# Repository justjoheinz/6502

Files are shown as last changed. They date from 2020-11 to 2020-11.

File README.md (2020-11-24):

# 6502 Microcomputer

## Bill of materials

[BOM](6502.csv)

## Schematic

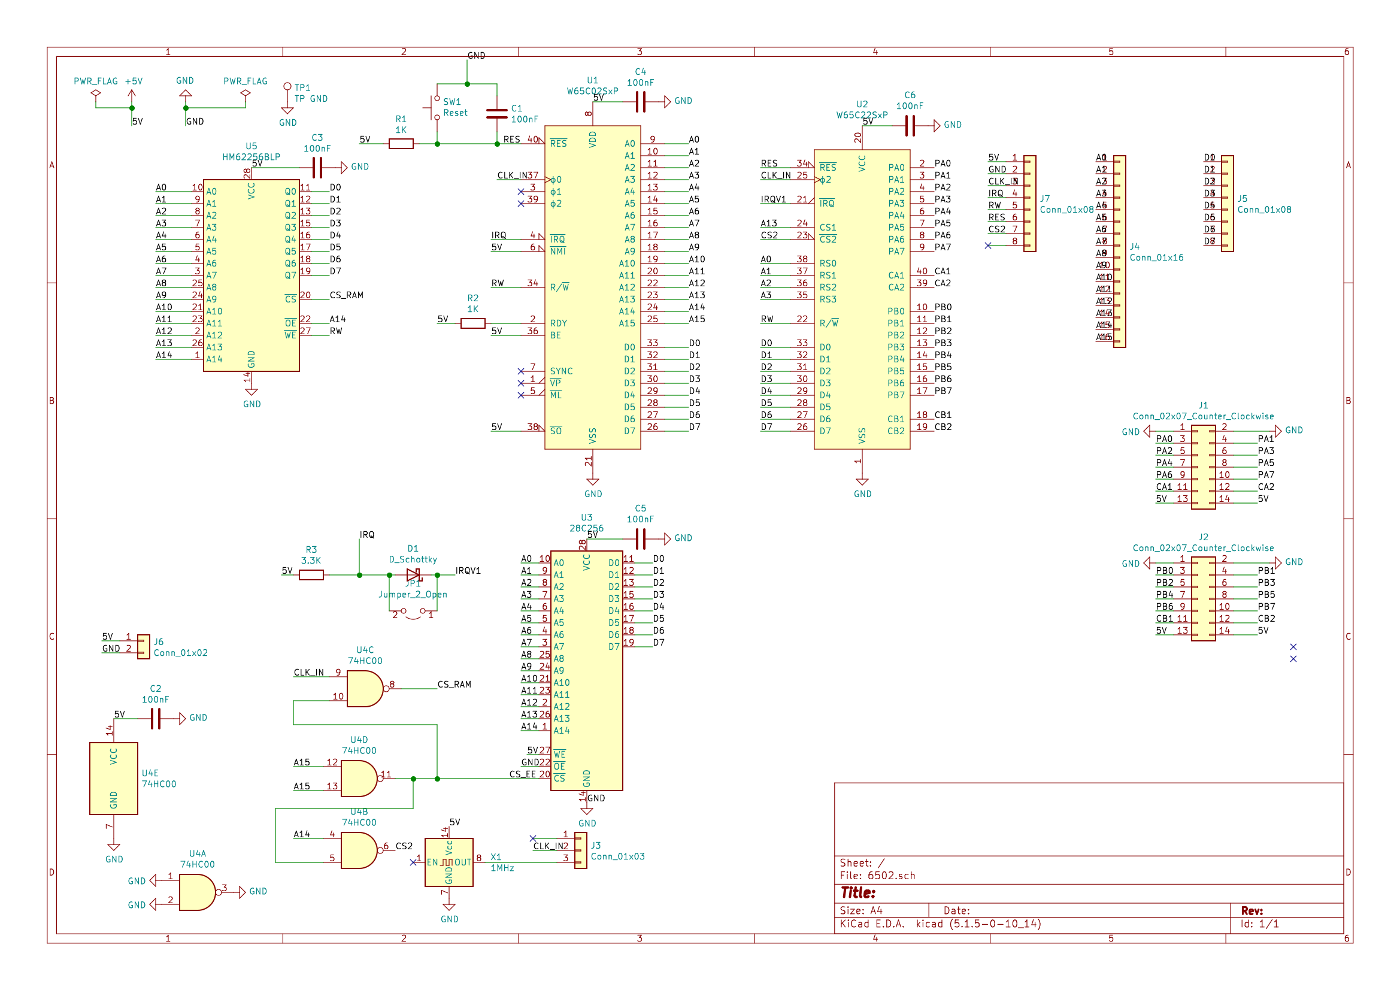
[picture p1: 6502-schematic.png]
Schematic


## PCB

### Mainboard

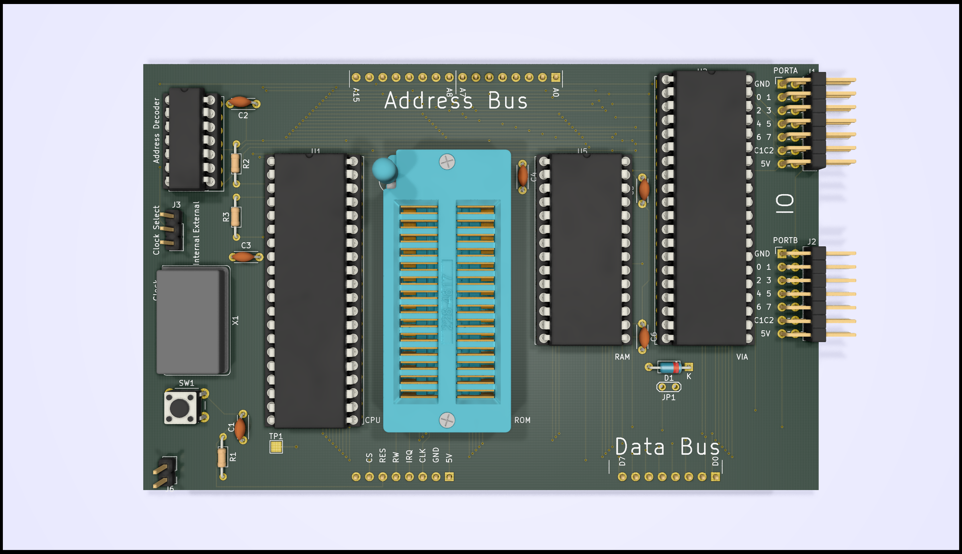
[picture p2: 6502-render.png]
Main board


### Prototype Board

Prototype Board

### Status

| Version | Status | Comment |
|---|---|---|
| v1.0.0  | unverified | boards send for production |

## Memory maps

| Type | From | To | Comments |
|---|---|---|---|
| RAM  | 0x0000 | 0x3FFF | |
| VIA  | 0x6000 | | A14, A15 - Registers via A0 - A3 |
| ROM  | 0x8000 | 0xFFFF | A15 High |

## ROM Source Code

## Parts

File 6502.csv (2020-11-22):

Comment | Designator | Footprint | LCSC Part #
100nF Unpolarized capacitor | C1,C2,C3,C4,C5,C6 | C_Disc_D4.3mm_W1.9mm_P5.00mm
D_Schottky Schottky diode | D1 | D_DO-35_SOD27_P7.62mm_Horizontal
Conn_02x07_Counter_Clockwise Generic connector, double row, 02x07, odd/even pin numbering scheme (row 1 odd numbers, row 2 even numbers), script generated (kicad-library-utils/schlib/autogen/connector/) | J1,J2 | PinHeader_2x07_P2.54mm_Horizontal
Conn_01x03 Generic connector, single row, 01x03, script generated (kicad-library-utils/schlib/autogen/connector/) | J3 | PinHeader_1x03_P2.54mm_Vertical
Conn_01x16 Generic connector, single row, 01x16, script generated (kicad-library-utils/schlib/autogen/connector/) | J4 | PinHeader_1x16_P2.54mm_Vertical
Conn_01x08 Generic connector, single row, 01x08, script generated (kicad-library-utils/schlib/autogen/connector/) | J5,J7 | PinHeader_1x08_P2.54mm_Vertical
Conn_01x02 Generic connector, single row, 01x02, script generated (kicad-library-utils/schlib/autogen/connector/) | J6 | PinHeader_1x02_P2.54mm_Vertical
Jumper_2_Open Jumper, 2-pole, open | JP1 | TestPoint_2Pads_Pitch2.54mm_Drill0.8mm
1K Resistor | R1,R2 | R_Axial_DIN0204_L3.6mm_D1.6mm_P7.62mm_Horizontal
3.3K Resistor | R3 | R_Axial_DIN0204_L3.6mm_D1.6mm_P7.62mm_Horizontal
Reset Push button switch, generic, two pins | SW1 | SW_PUSH_6mm
TP GND test point | TP1 | TestPoint_Pad_2.0x2.0mm
W65C02SxP W65C02S 8-bit CMOS General Purpose Microprocessor, DIP-40 | U1 | DIP-40_W15.24mm_Socket_LongPads
W65C22SxP W65C22S CMOS Versatile Interface Adapter (VIA), 20-pin I/O, 2 Timer/Counters, DIP-40 | U2 | DIP-40_W15.24mm_Socket_LongPads
28C256 Paged Parallel EEPROM 256Kb (32K x 8), DIP-28/SOIC-28 | U3 | DIP_Socket-28_W11.9_W12.7_W15.24_W17.78_W18.5_3M_228-1277-00-0602J
74HC00 quad 2-input NAND gate | U4 | DIP-14_W7.62mm_Socket_LongPads
HM62256BLP 32,768-word × 8-bit High Speed CMOS Static RAM, 70ns, DIP-28 | U5 | DIP-28_W15.24mm_Socket_LongPads
1MHz Crystal Clock Oscillator, DIP14-style metal package | X1 | Oscillator_DIP-14

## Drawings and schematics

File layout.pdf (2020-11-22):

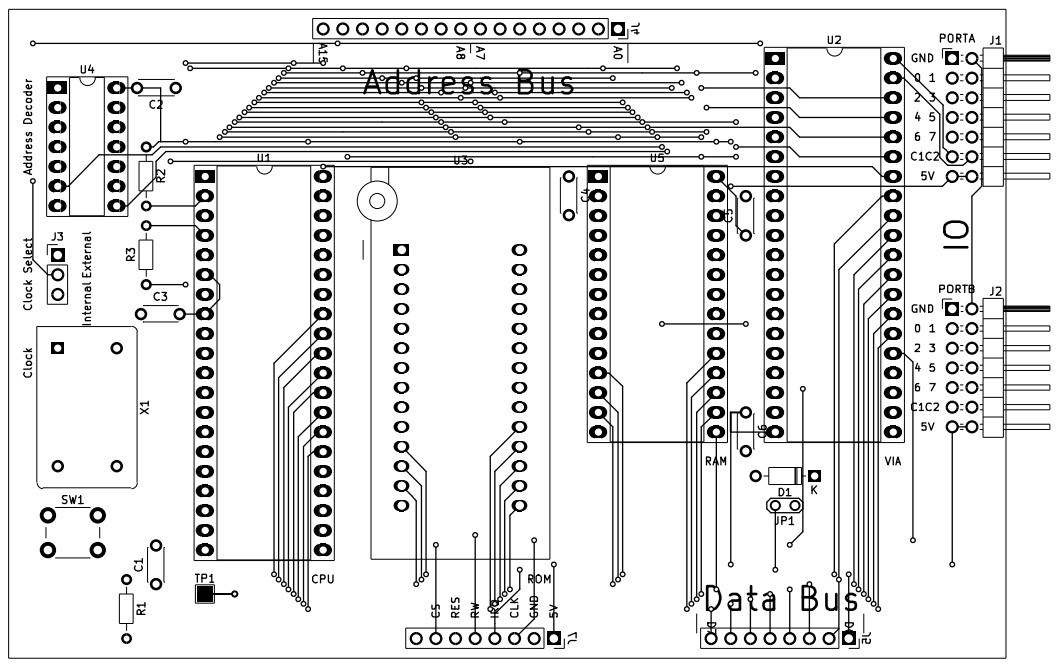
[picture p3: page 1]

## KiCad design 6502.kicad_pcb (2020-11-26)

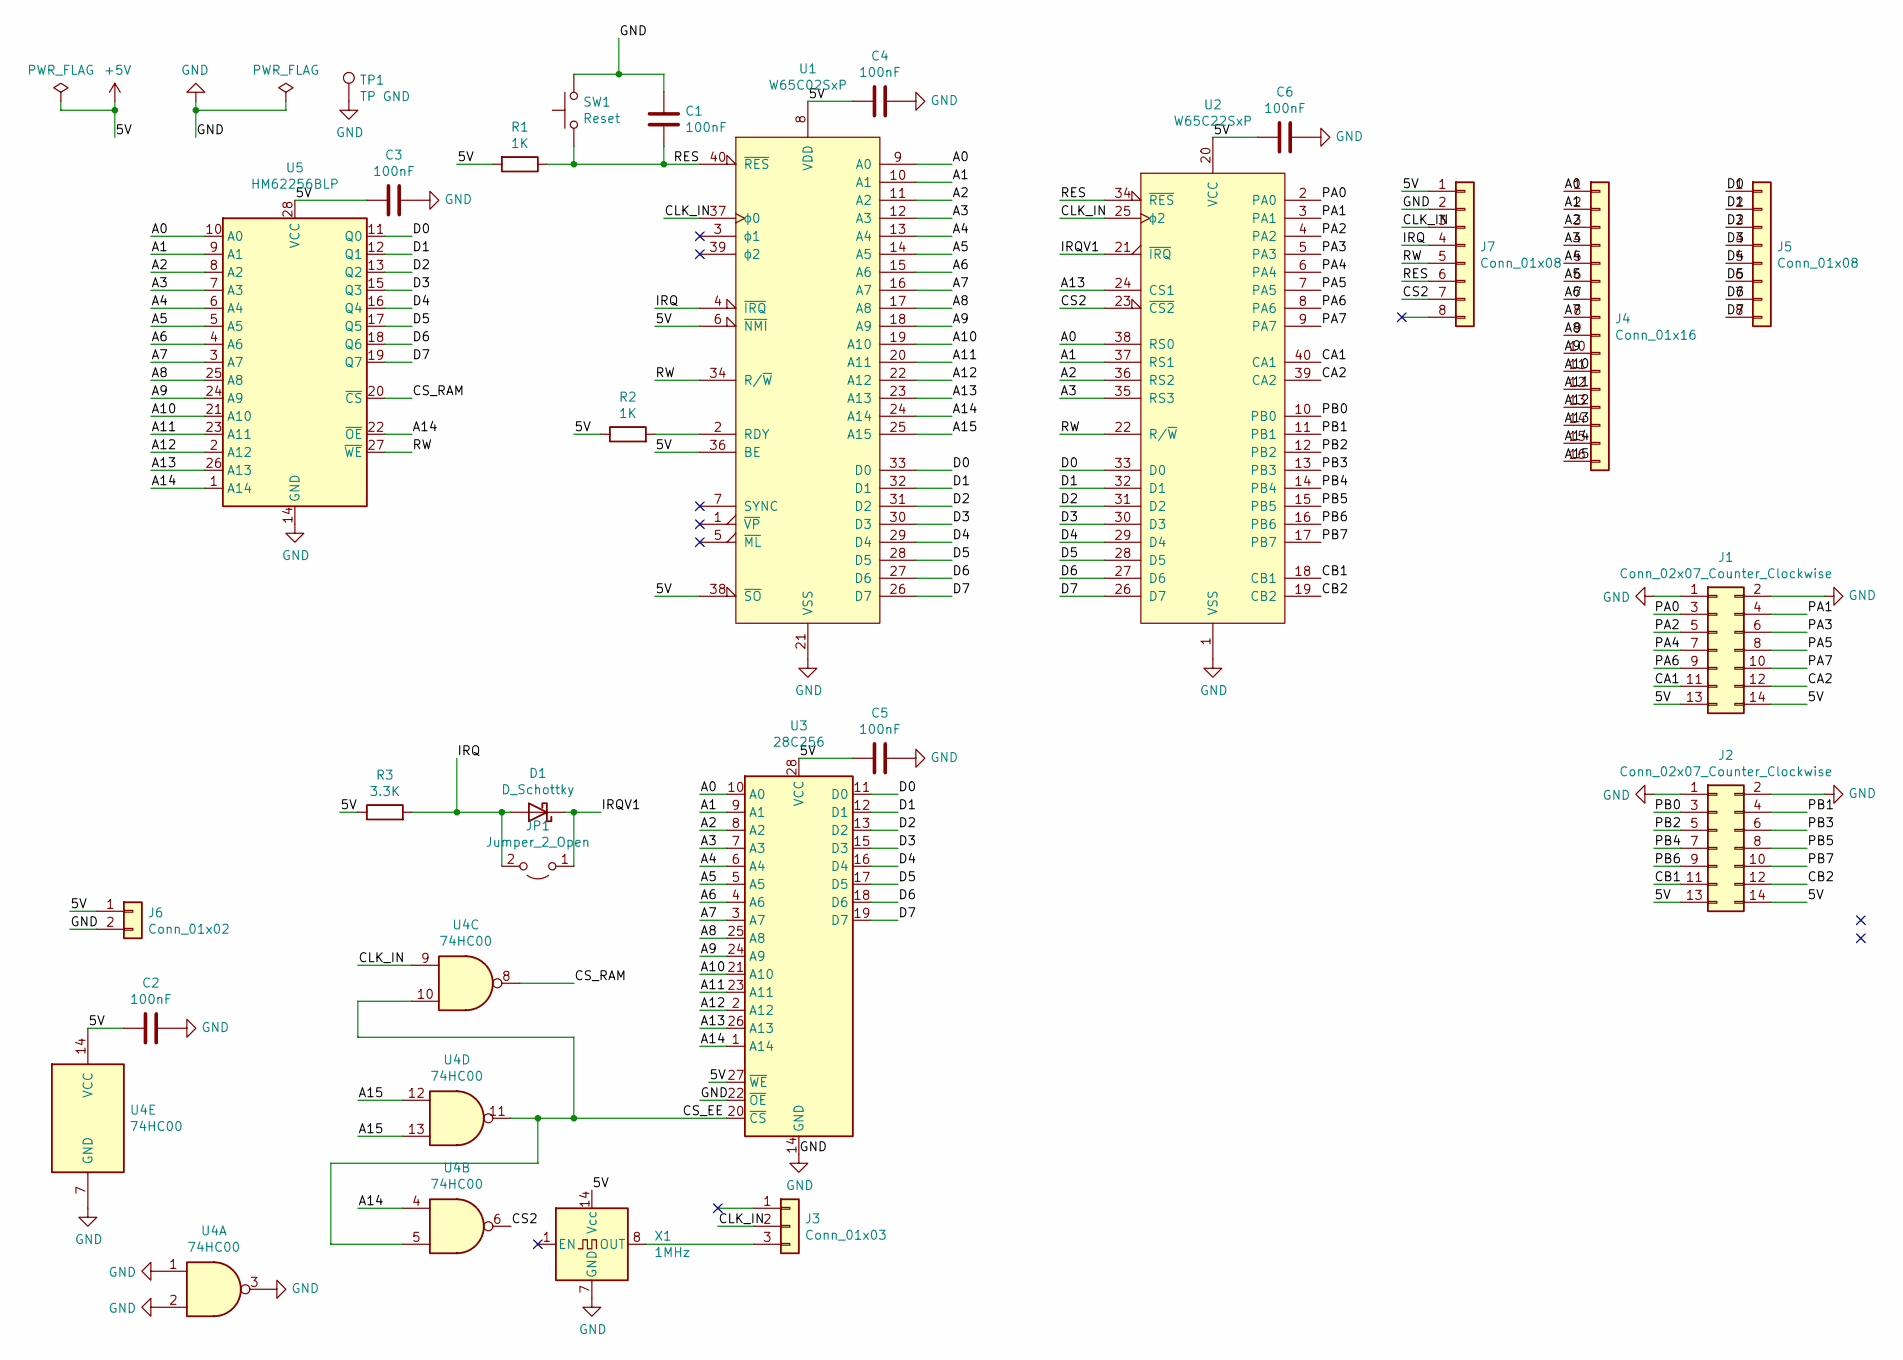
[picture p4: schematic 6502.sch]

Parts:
C1, C2, C3, C4, C5, C6: 100nF; C_Disc_D4.3mm_W1.9mm_P5.00mm
D1: D_Schottky; D_DO-35_SOD27_P7.62mm_Horizontal
J1, J2: Conn_02x07_Counter_Clockwise; PinHeader_2x07_P2.54mm_Horizontal
J3: Conn_01x03; PinHeader_1x03_P2.54mm_Vertical
J4: Conn_01x16; PinHeader_1x16_P2.54mm_Vertical
J5, J7: Conn_01x08; PinHeader_1x08_P2.54mm_Vertical
J6: Conn_01x02; PinHeader_1x02_P2.54mm_Vertical
JP1: Jumper_2_Open; TestPoint_2Pads_Pitch2.54mm_Drill0.8mm
R1, R2: 1K; R_Axial_DIN0204_L3.6mm_D1.6mm_P7.62mm_Horizontal
R3: 3.3K; R_Axial_DIN0204_L3.6mm_D1.6mm_P7.62mm_Horizontal
SW1: Reset; SW_PUSH_6mm
TP1: TP GND; TestPoint_Pad_2.0x2.0mm
U1: W65C02SxP; DIP-40_W15.24mm_Socket_LongPads
U2: W65C22SxP; DIP-40_W15.24mm_Socket_LongPads
U3: 28C256; DIP_Socket-28_W11.9_W12.7_W15.24_W17.78_W18.5_3M_228-1277-0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
U4: 74HC00; DIP-14_W7.62mm_Socket_LongPads
U5: HM62256BLP; DIP-28_W15.24mm_Socket_LongPads
X1: 1MHz; Oscillator_DIP-14

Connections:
+5V: C2.2, C3.2, C4.2, C5.1, C6.1, J1.13, J1.14, J2.13, J2.14, J6.1, J7.1, R1.2, R2.1, R3.1, U1.6 (~NMI), U1.8 (VDD), U1.36 (BE), U1.38 (~SO), U2.20 (VCC), U3.27 (~WE), U3.28 (VCC), U4.14 (VCC), U5.28 (VCC), X1.14 (Vcc)
/A0: J4.1, U1.9 (A0), U2.38 (RS0), U3.10 (A0), U5.10 (A0)
/A1: J4.2, U1.10 (A1), U2.37 (RS1), U3.9 (A1), U5.9 (A1)
/A2: J4.3, U1.11 (A2), U2.36 (RS2), U3.8 (A2), U5.8 (A2)
/A3: J4.4, U1.12 (A3), U2.35 (RS3), U3.7 (A3), U5.7 (A3)
/A4: J4.5, U1.13 (A4), U3.6 (A4), U5.6 (A4)
/A5: J4.6, U1.14 (A5), U3.5 (A5), U5.5 (A5)
/A6: J4.7, U1.15 (A6), U3.4 (A6), U5.4 (A6)
/A7: J4.8, U1.16 (A7), U3.3 (A7), U5.3 (A7)
/A8: J4.9, U1.17 (A8), U3.25 (A8), U5.25 (A8)
/A9: J4.10, U1.18 (A9), U3.24 (A9), U5.24 (A9)
/A10: J4.11, U1.19 (A10), U3.21 (A10), U5.21 (A10)
/A11: J4.12, U1.20 (A11), U3.23 (A11), U5.23 (A11)
/A12: J4.13, U1.22 (A12), U3.2 (A12), U5.2 (A12)
/A13: J4.14, U1.23 (A13), U2.24 (CS1), U3.26 (A13), U5.26 (A13)
/A14: J4.15, U1.24 (A14), U3.1 (A14), U4.4, U5.1 (A14), U5.22 (~OE)
/A15: J4.16, U1.25 (A15), U4.12, U4.13
/CA1: J1.11, U2.40 (CA1)
/CA2: J1.12, U2.39 (CA2)
/CB1: J2.11, U2.18 (CB1)
/CB2: J2.12, U2.19 (CB2)
/CLK_IN: J3.2, J7.3, U1.37 (ϕ0), U2.25 (ϕ2), U4.9
/CS2: J7.7, U2.23 (~CS2), U4.6
/CS_EE: U3.20 (~CS), U4.5, U4.10, U4.11
/CS_RAM: U4.8, U5.20 (~CS)
/D0: J5.1, U1.33 (D0), U2.33 (D0), U3.11 (D0), U5.11 (Q0)
/D1: J5.2, U1.32 (D1), U2.32 (D1), U3.12 (D1), U5.12 (Q1)
/D2: J5.3, U1.31 (D2), U2.31 (D2), U3.13 (D2), U5.13 (Q2)
/D3: J5.4, U1.30 (D3), U2.30 (D3), U3.15 (D3), U5.15 (Q3)
/D4: J5.5, U1.29 (D4), U2.29 (D4), U3.16 (D4), U5.16 (Q4)
/D5: J5.6, U1.28 (D5), U2.28 (D5), U3.17 (D5), U5.17 (Q5)
/D6: J5.7, U1.27 (D6), U2.27 (D6), U3.18 (D6), U5.18 (Q6)
/D7: J5.8, U1.26 (D7), U2.26 (D7), U3.19 (D7), U5.19 (Q7)
/IRQ: D1.2 (A), J7.4, JP1.2 (B), R3.2, U1.4 (~IRQ)
/IRQV1: D1.1 (K), JP1.1 (A), U2.21 (~IRQ)
/PA0: J1.3, U2.2 (PA0)
/PA1: J1.4, U2.3 (PA1)
/PA2: J1.5, U2.4 (PA2)
/PA3: J1.6, U2.5 (PA3)
/PA4: J1.7, U2.6 (PA4)
/PA5: J1.8, U2.7 (PA5)
/PA6: J1.9, U2.8 (PA6)
/PA7: J1.10, U2.9 (PA7)
/PB0: J2.3, U2.10 (PB0)
/PB1: J2.4, U2.11 (PB1)
/PB2: J2.5, U2.12 (PB2)
/PB3: J2.6, U2.13 (PB3)
/PB4: J2.7, U2.14 (PB4)
/PB5: J2.8, U2.15 (PB5)
/PB6: J2.9, U2.16 (PB6)
/PB7: J2.10, U2.17 (PB7)
/RES: C1.2, J7.6, R1.1, SW1.1, U1.40 (~RES), U2.34 (~RES)
/RW: J7.5, U1.34 (R/~W), U2.22 (R/~W), U5.27 (~WE)
GND: C1.1, C2.1, C3.1, C4.1, C5.2, C6.2, J1.1, J1.2, J2.1, J2.2, J6.2, J7.2, SW1.2, TP1.1, U1.21 (VSS), U2.1 (VSS), U3.14 (GND), U3.22 (~OE), U4.1, U4.2, U4.3, U4.7 (GND), U5.14 (GND), X1.7 (GND)
unnamed: J3.3, X1.8 (OUT)
unnamed: R2.2, U1.2 (RDY)

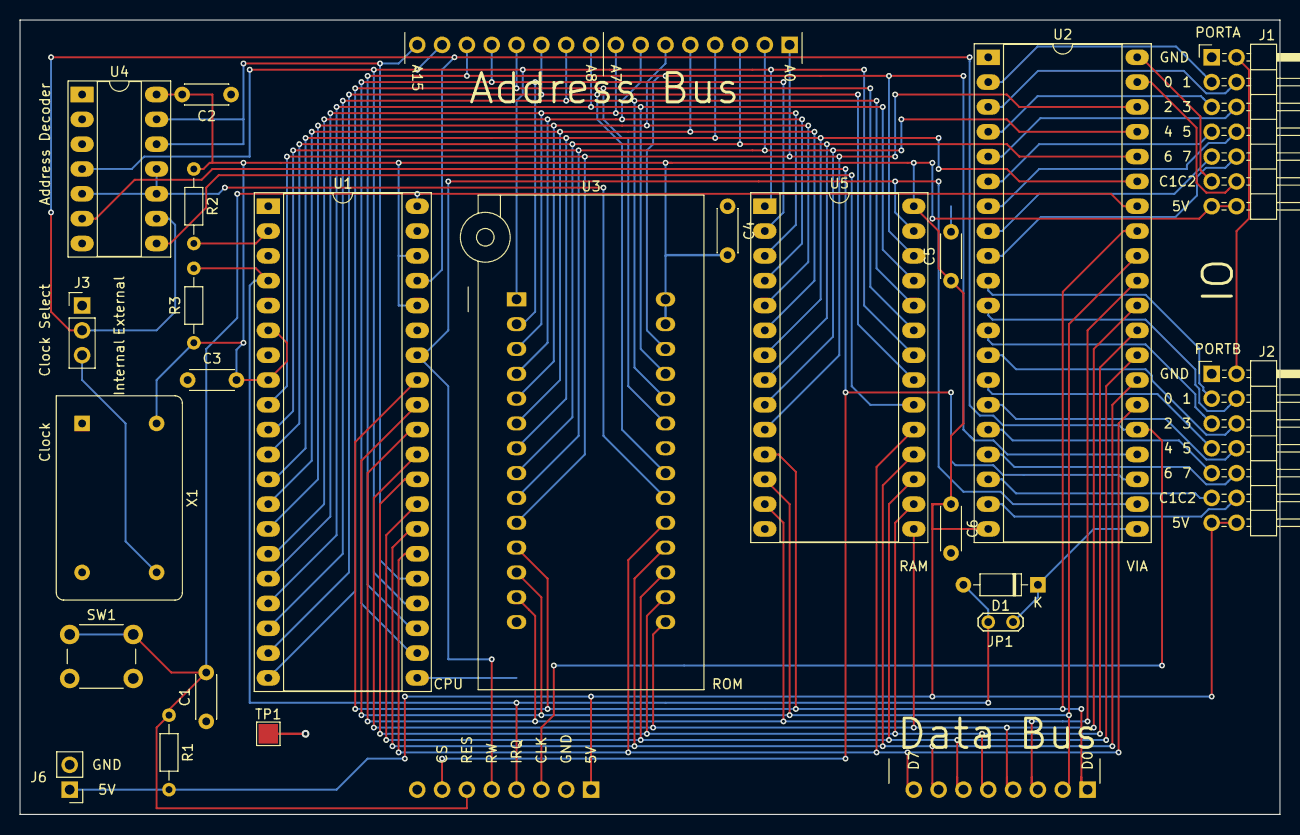
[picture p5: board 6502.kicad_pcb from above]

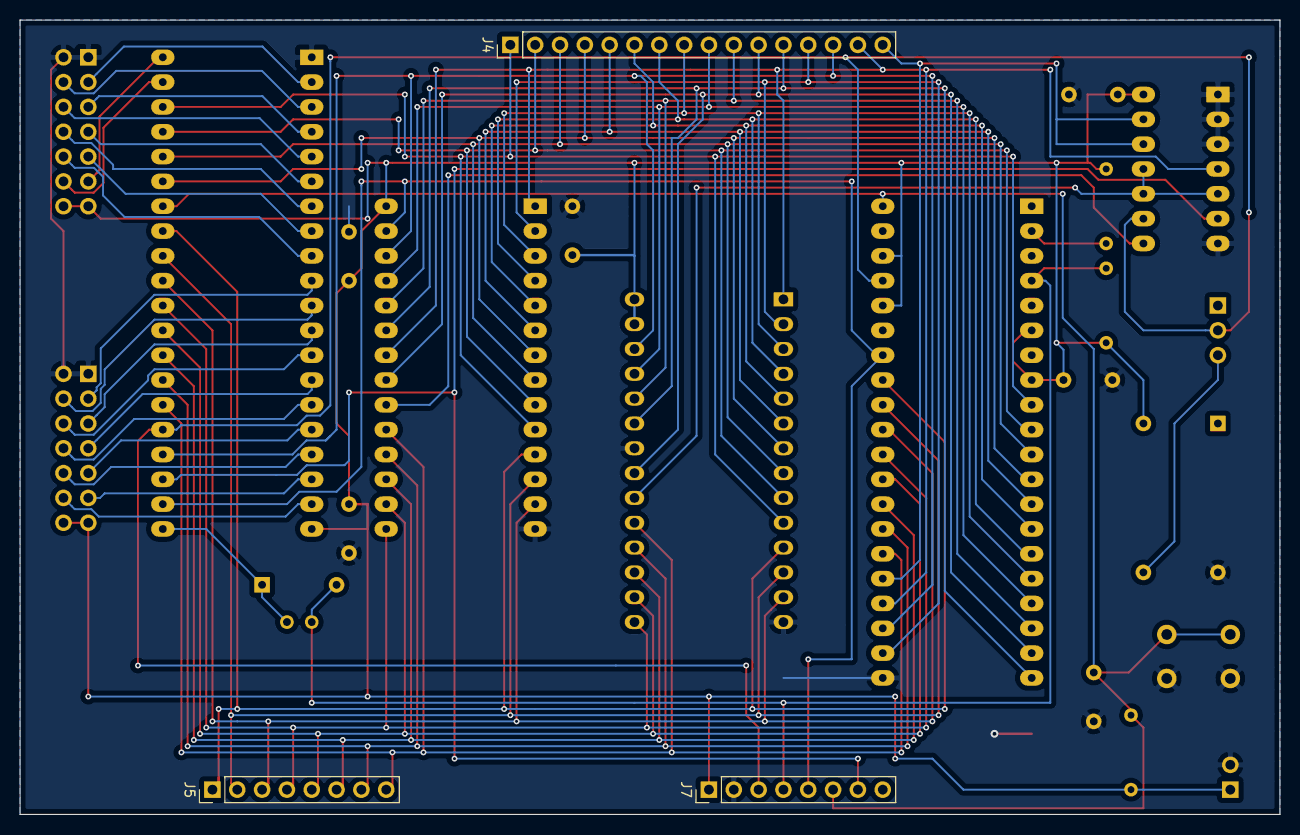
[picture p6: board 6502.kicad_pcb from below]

Board: 2 copper layers, 128.9 x 81.3 mm, 26 parts (3 on the bottom side), 56 nets.

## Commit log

2020-11-22 Initial version
    [6502-B_Cu.gbr, 6502-B_Mask.gbr, 6502-B_Paste.gbr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]
2020-11-22 Add BOM
    [6502.csv]
2020-11-24 Removed pinheaders from 3D view
    [6502-bb.kicad_pcb]
2020-11-26 Add power supply text to silkscreen
    [6502.kicad_pcb]
